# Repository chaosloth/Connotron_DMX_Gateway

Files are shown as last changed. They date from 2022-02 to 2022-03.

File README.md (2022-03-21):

# ESP32 ArtNet to DMX Gateway

This project allows for receiving ArtNet messages via WIFI and transmitting ANSI-ESTA E1.11 DMX-512A using an Espressif ESP32. It is based on two libraries for ArtNet and DMX messaging which individually have a ton of configurability. By default this project will open up a WIFI configuration portal after a _double reset_ where the WIFI credentials and ArtNet Universe may be configured. The output circuitry has been texted with [MAX485 TTL UART to RS485](https://core-electronics.com.au/ttl-uart-to-rs485-converter-module.html) module along with MAX485 chips directly. 

Click the link below to see it in action

See it in action

## Contents

- [Overview](#overview)
  - [Flow](#flow)
  - [Stack](#stack)
- [Prototype 1](#prototype-1)
- [Prototype 2](#prototype-2)
  - [Schematic](#schematic)
  - [PCB Layout](#pcb-layout)
  - [PCB Render](#pcb-render)
  - [Enclosure](#enclosure)
- [Library Installation](#library-installation)
  - [ArtNet](#artnet)
  - [ESP DMX](#esp-dmx)
  - [WIFI Manager](#wifi-manager)
- [Hardware](#hardware)
  - [UART Pins](#uart-pins)

## Overview

### Stack
Building on the ESP Core, this project can accept physical DMX connections (RJ45, XLR) along with connecting to WIFI to accept ArtNet messagse. Whilst it is possible to accept ArtNet broadcast messages, the reality of WIFI connections is that many packets are lost, hence it is recommended that UNICAST be configured for the upstream ArtNet controller.

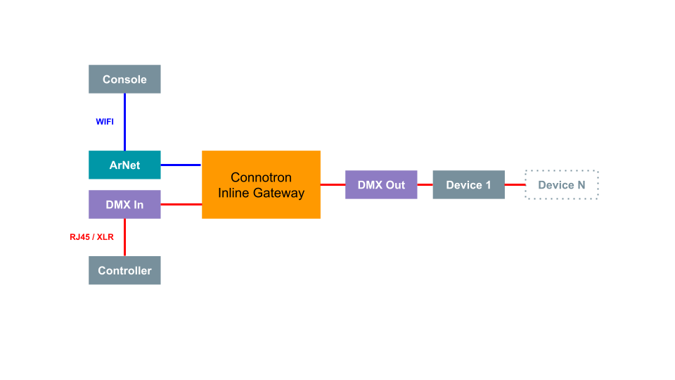
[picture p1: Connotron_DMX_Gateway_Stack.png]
Stack


### Flow

All incoming DMX messages are forwarded by default to the DMX Out port unless ArtNet messaging is being received, in which case Incoming DMX messages are dropped and the configured ArtNet universe messages are sent via the DMX Out port. The Gateway is configured to forward exactly one ArtNet universe to the DMX Output port. A Universe ID is configured as part of the WIFI setup, by default Universe 1 is configured.

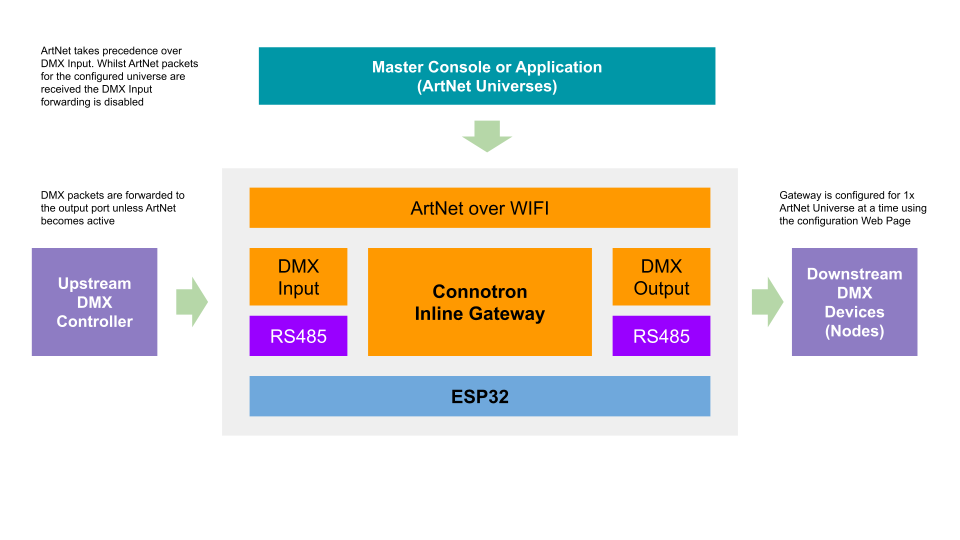
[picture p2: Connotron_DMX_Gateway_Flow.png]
Flow


## Prototype 0

The proto board uses off the shelf modules hand soldered with perfboard

Proto Board Proto

## Prototype 1

The proto board uses off the shelf modules to enable RS485 (DMX) communication between devices, though you can use the MAX485 chip directly. Basic board outline via EasyEDA.

Proto Board Proto

## Prototype 2

A second version of the board created use EasyEDA and Fusion 360 for custom board and case design.

*Note*: ESP module does not have any flash, use version v3

### Schematic

Schematic

### PCB Layout

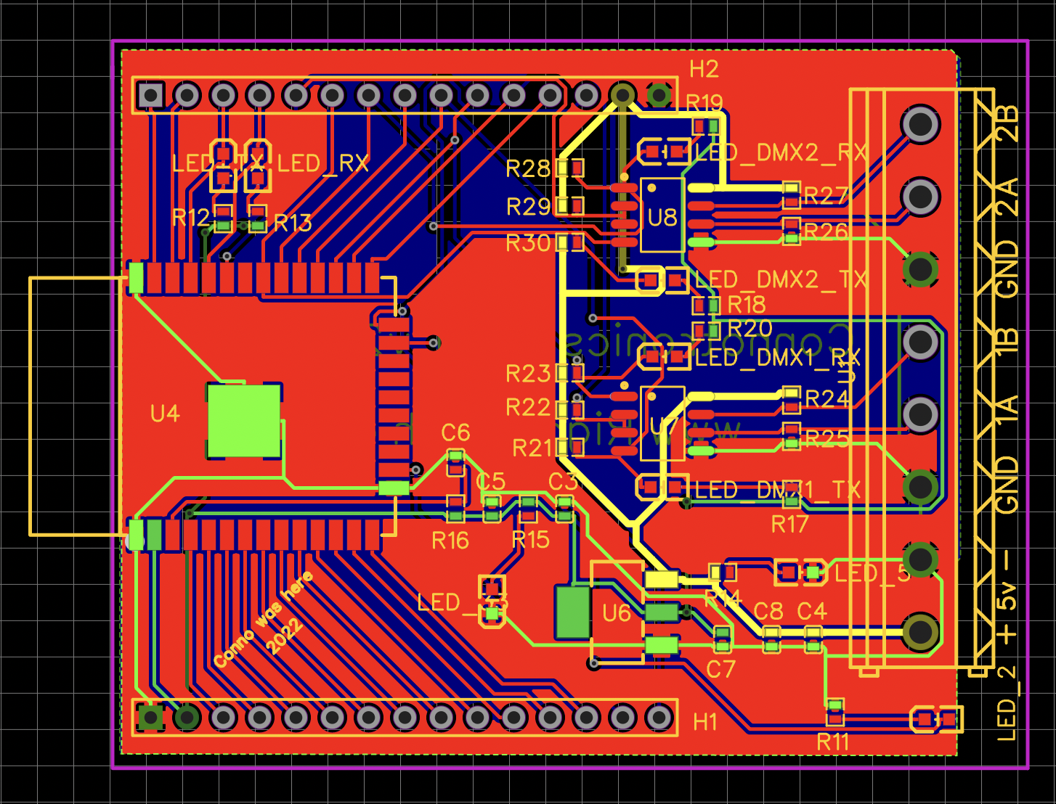
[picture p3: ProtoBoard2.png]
Silkscreen


### PCB Render

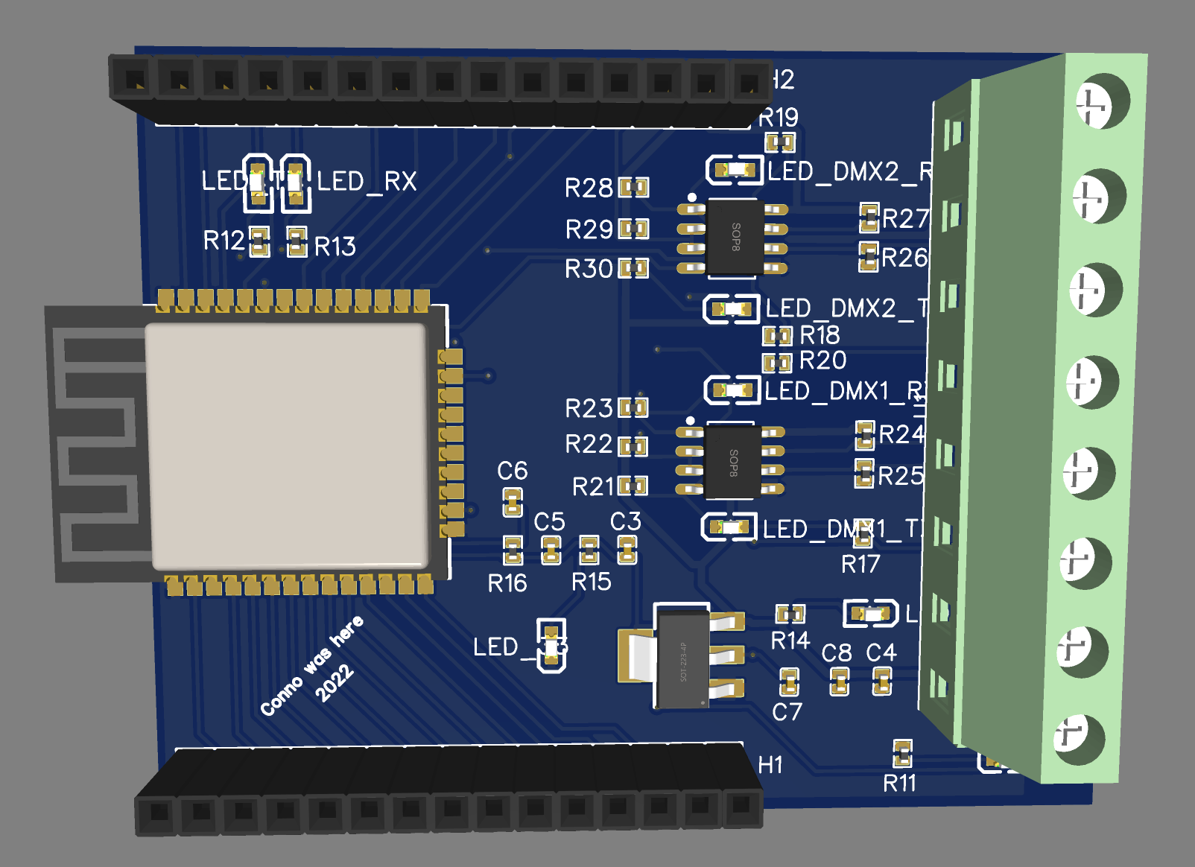
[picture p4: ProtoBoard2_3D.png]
3D Render


### Enclosure

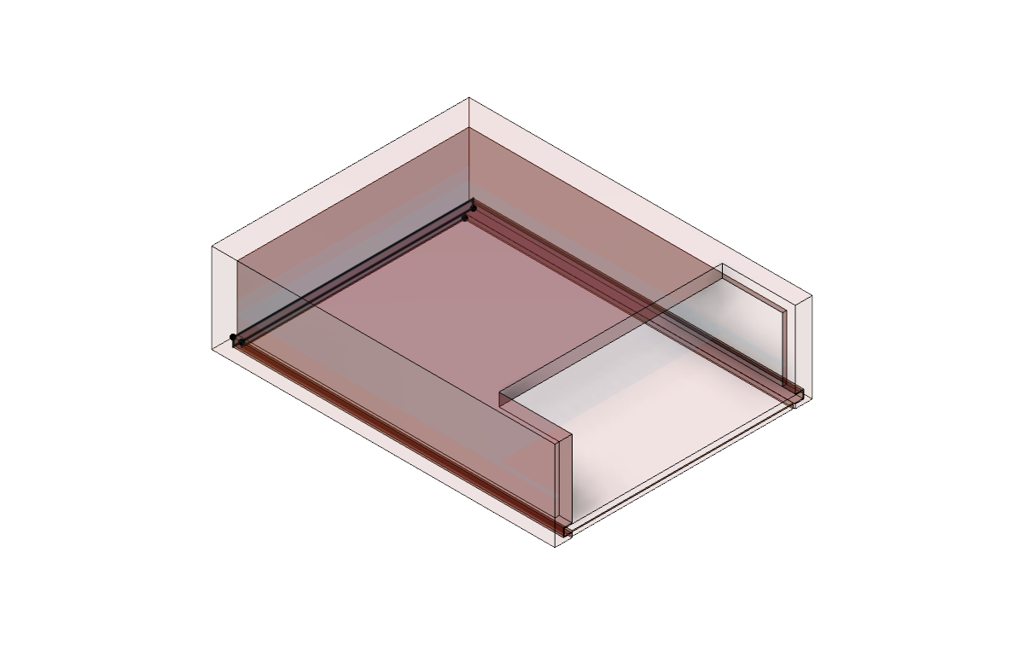
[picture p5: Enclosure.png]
Enclosure


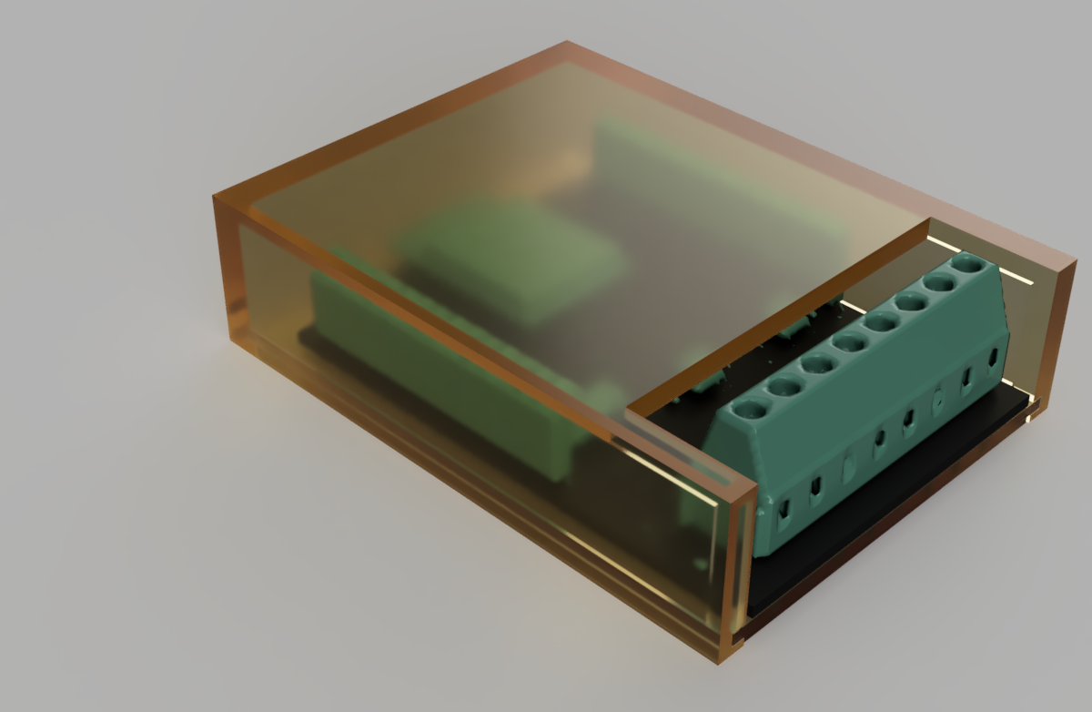
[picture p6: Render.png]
Render


## Library Installation

This project requires the Arduino-ESP32 framework version 2.0.0 or newer. To install the correct framework, follow Espressif's instructions on the Arduino-ESP32 documentation page [here](https://docs.espressif.com/projects/arduino-esp32/en/latest/installing.html).

### ArtNet

This project uses [ArtnetWifi](https://github.com/rstephan/ArtnetWifi) from Stephan Ruloff as the means to receive ArtNet packets

Tested with 1.4.0 -- Install this via Arduino Library Manager

### ESP DMX

This project uses [esp_dmx](https://github.com/someweisguy/esp_dmx) from Mitch Weisbrod as the means to transmit and receive DMX messages

Tested with 1.1.3 -- Install this via Arduino Library Manager

### WIFI Manager

This project uses [ESP Async WIFI Manager](https://github.com/khoih-prog/ESPAsync_WiFiManager) from Khoi Hoangx as the means to configure WIFI credentials

Tested with 1.12.0 -- Install this via Arduino Library Manager

## Hardware

RS485 to TTL UART is performed by the MAX485 (or similar) IC. Wired as follows. UART 2 on the ESP is used for communications on the default pins. This can be changed to any available UART if required, note that the ESP32 has the ability to remap UART pins to any GPIO, with the esp_dmx library providing a function to set the pins. 

Note that if this is setup to transmit DMX messages only, then RE, DE can simply be pulled low to GND

#### DMX Port - Output

Note receive is not connected in this case

| Function			  | ESP PIN | MAX PIN 	|
| --- |:---:| ---:|
| Transmit			  | 17			 | DI 		 |
| Transmit Enable	| 4 			 | RE 	 	|
| Receive Enable	| 4 			 | DE 	 	|
| Receive			 | NC (16)	 | RO 	 	|

#### DMX Port - Input

Note transmit is not connected in this case

| Function | ESP PIN | MAX PIN |
| --- |:---:| ---:|
| Transmit | NC (19) | DI |
| Transmit Enable | 21 | RE |
| Receive Enable  | 21 | DE |
| Receive | 18 | RO |

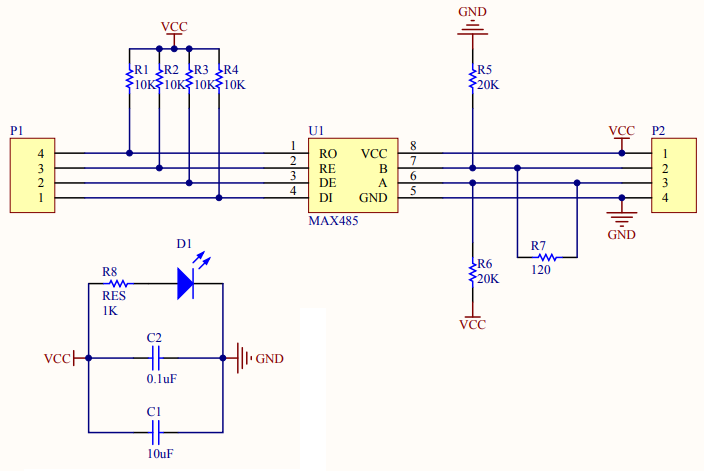
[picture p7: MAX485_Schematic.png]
Schematic MAX485


### UART Pins

Use the esp_dmx function call to change the UART GPIO pins to non-standard pinouts

```
esp_err_t dmx_set_pin(dmx_port_t dmx_num, int tx_io_num, int rx_io_num, int rts_io_num)
```

Example:
```
dmx_port_t dmxPort = 2;
int transmitPin = 17;
int receivePin = 16;
int enablePin = 21;

dmx_set_pin(dmxPort, transmitPin, receivePin, enablePin);
```

## Uploading Firmware
### Manually

Manual upload to board, using **using esptool v3.2**
```
esptool.py --port /dev/cu.usbserial-1110  --before default_reset \
  --after hard_reset write_flash -z --flash_mode dio \
  --flash_freq 80m  \
  0xe000 boot_app0.bin \
  0x1000 ESP32_ArtNet_DMX_Gateway.ino.bootloader.bin \
  0x10000 ESP32_ArtNet_DMX_Gateway.ino.bin \
  0x8000 ESP32_ArtNet_DMX_Gateway.ino.partitions.bin
  ```

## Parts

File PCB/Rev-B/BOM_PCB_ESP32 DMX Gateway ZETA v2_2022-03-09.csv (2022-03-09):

ID | Name | Designator | Footprint | Quantity | Manufacturer Part | Manufacturer | Supplier | Supplier Part | Price | Pins | 3DModel | JLCPCB Part Class | LCSC Assembly | Contributor | SMT Type | image | link
1 | 19-217/GHC-YR1S2/3T | LED_2,LED_5,LED_33,LED_DMX1_RX,LED_DMX1_TX,LED_DMX2_RX,LED_DMX2_TX,LED_RX,LED_TX | LED0603-R-RD | 9 | 19-217/GHC-YR1S2/3T | EVERLIGHT | LCSC | C72043 | 0.029 | 2 | LED0603_L1.6-W0.8-H0.6 | Basic Part |  | 官方封装库 |  |  | https://lcsc.com/product-detail/Light-Emitting-Diodes-LED_Hubei-KENTO-Elec-0603-Green_C12624.html
2 | DB127V-5.0-8P-GN-S | U1 | CONN-TH_8P-P5.08_DB128L-5.0-8P-GN-S | 1 | DB128L-5.0-8P-GN-S | DIBO | LCSC | C430596 | 0.528 | 8 | CONN-TH_8P-P5.08_DB128L-5.0-8P-GN-S | Extended Part |  | LCSC |  |  | https://item.szlcsc.com/426241.html
3 | 100nF | C3,C4,C6 | C0402 | 3 | CL05B104KO5NNNC | SAMSUNG | LCSC | C1525 | 0.001 | 2 | C0402_L1.0-W0.5-H0.5 |  | Yes | layout | Basic |  | https://item.szlcsc.com/319796.html
4 | 10uF | C5,C7,C8 | C0402 | 3 | CL05A106MQ5NUNC | SAMSUNG | LCSC | C15525 | 0.005 | 2 | C0402_L1.0-W0.5-H0.5 |  | Yes | layout | Basic |  | https://item.szlcsc.com/319796.html
5 | HDR-F-2.54_1x15 | H1,H2 | HDR-F-2.54_1X15 | 2 |  |  | LCSC | C124408 | 0.203 | 15 | HDR-F-2.54_1x15 |  |  | LCEDA_Lib
6 | 470 | R11,R12,R13,R14,R15,R17,R18,R19,R20 | R0402 | 9 | 0402WGF4700TCE | UniOhm | LCSC | C25117 | 0.001 | 2 | R0402_L1.0-W0.5-H0.5 |  | Yes | layout | Basic |  | https://item.szlcsc.com/323315.html
7 | 12K | R16 | R0402 | 1 | 0402WGF1202TCE | UniOhm | LCSC | C25752 | 0.001 | 2 | R0402_L1.0-W0.5-H0.5 |  | Yes | layout | Basic |  | https://item.szlcsc.com/323315.html
8 | 10K | R21,R22,R23,R28,R29,R30 | R0402 | 6 | 0402WGF4700TCE | UniOhm | LCSC | C25117 | 0.001 | 2 | R0402_L1.0-W0.5-H0.5 |  | Yes | layout | Basic |  | https://item.szlcsc.com/323315.html
9 | 20K | R24,R25,R26,R27 | R0402 | 4 | 0402WGF4700TCE | UniOhm | LCSC | C25117 | 0.001 | 2 | R0402_L1.0-W0.5-H0.5 |  | Yes | layout | Basic |  | https://item.szlcsc.com/323315.html
10 | AMS1117-3.3 | U6 | SOT-223-3_L6.5-W3.4-P2.30-LS7.0-BR | 1 | AMS1117-3.3 | AMS | LCSC | C6186 | 0.18 | 4 | SOT-223-4P_L6.5-W3.5-H1.6-LS7.0-P2.30 |  | Yes | LCSC | Basic | //image.lceda.cn/szlcsc/C6186.jpg | https://item.szlcsc.com/410724.html
11 | MAX485ED | U7,U8 | SOP-8_L4.9-W3.9-P1.27-LS6.0-BL | 2 | MAX485ED | HTC Korea TAEJIN Tech | LCSC | C481667 | 0.395 | 8 | SOP-8_L4.9-W3.9-H1.45-LS6.0-P1.27 | Extended Part |  | LCSC |  |  | https://item.szlcsc.com/383602.html
12 | ESP32-WROOM-32E(16MB) | U4 | WIFI-SMD_ESP32-WROOM-32E-A | 1 | ESP32-WROOM-32E(16MB) | Espressif Systems | LCSC | C701343 | 5.11 | 47 |  | Extended Part |  | LCSC |  |  | https://img.jlc.com/pdf/applyPasteComponent/2022-02-19/286240A/9c72ea5c3be84b1e91d87726b093e6ca/esp32-wroom-32e_esp32-wroom-32ue_datasheet_cn.pdf

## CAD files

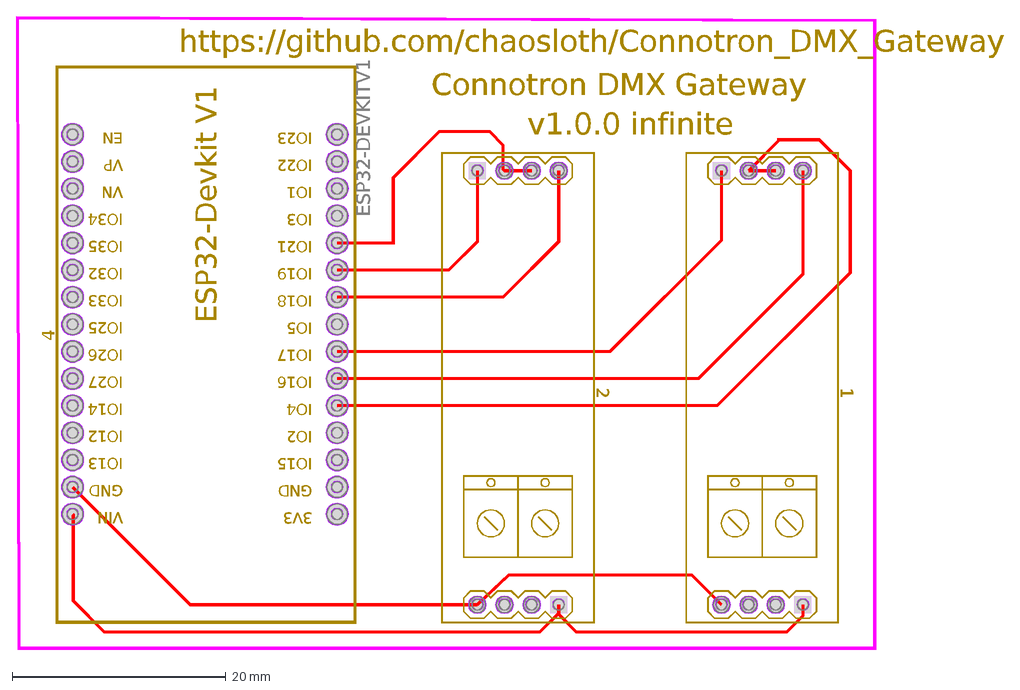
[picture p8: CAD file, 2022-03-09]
Enclosure/Rev A Board/V1/PCB_ESP32 DMX Gateway_2022-03-01.dxf
https://github.com/chaosloth/Connotron_DMX_Gateway
Connotron DMX Gateway
v1.0.0 infinite
1
2
4
3V3
GND
IO15
IO2
IO4
IO16
IO17
IO5
IO18
IO19
IO21
IO3
IO1
IO22
IO23
VIN
IO13
IO12
IO14
IO27
IO26
IO25
IO33
IO32
IO35
IO34
VN
VP
EN
ESP32-Devkit V1
ESP32-DEVKITV1

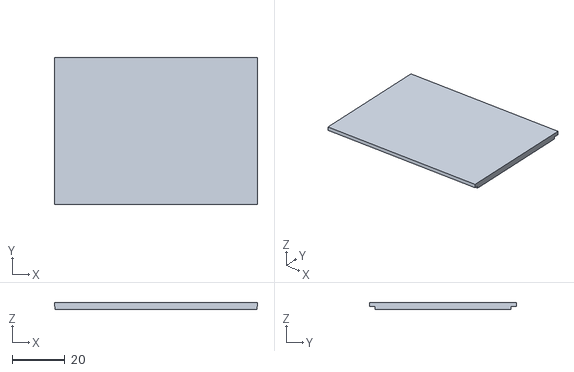
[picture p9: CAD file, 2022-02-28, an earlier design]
Enclosure/V2/Lid.stl
77.0 x 55.6 x 2.80

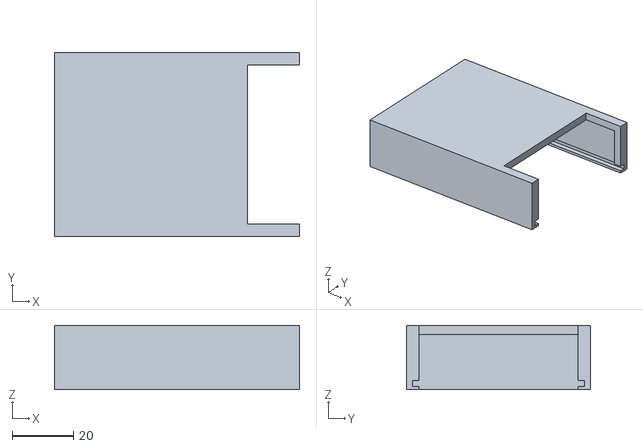
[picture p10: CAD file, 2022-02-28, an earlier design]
Enclosure/V3/Middle body.stl
80.0 x 60.0 x 20.9

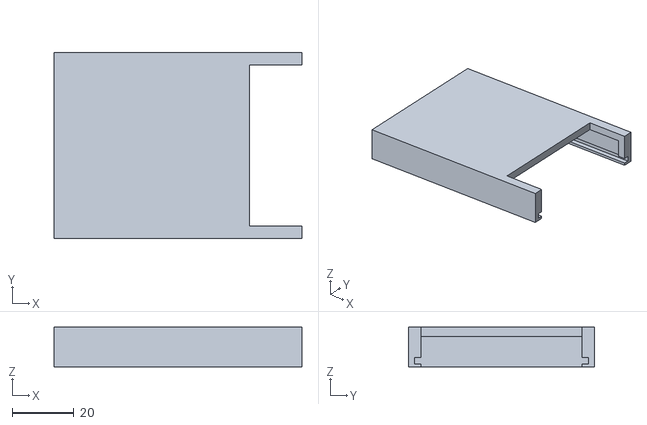
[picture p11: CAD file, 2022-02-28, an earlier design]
Enclosure/V2/Combineed box.stl
80.0 x 60.0 x 12.9

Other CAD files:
Enclosure/V3/Lid.stl

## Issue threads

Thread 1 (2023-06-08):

trouble with webserver

maracasas, 2023-06-08:
greetings.

i successfully compiled this file:
https://github.com/chaosloth/Connotron_DMX_Gateway/blob/master/ESP32_ArtNet_DMX_Gateway/ESP32_ArtNet_DMX_Gateway.ino

i see the esp32 is receiving artnet data, so i assume the device and bin works as intended

but for dear life, i can not access the webserver

i tried using the ip that m router give to the esp32, and the host name that shows in serial printer on arduino ide.

can you point me where is the problem please?

i am using all the libraries you shared + ESPAsyncWebServer from the same author of ESPAsync_WiFiManager

chaosloth, 2023-07-13:
Hey @maracasas sorry to hear it's not working, can you send me some additional info to help debug, e.g.

- What board are you using?
- Can you add the serial output upon startup?
- Can you ping the <whatever>.local mDNS name?
- Can you telnet to the IP/DNS on port 80?

chaosloth, 2023-07-20:
Cool glad it worked out. You're right it is only used for OTA, you could of course roll your own web interface and call api end points to configure it.

As for changing the DMX (IN/OUT) yes this is certainly possible, you can also add more DMX interfaces, so long as you have free UARTS.

Aside note, I have a bunch of left over board with (Prototype 1). I'm happy to send you a couple. Direct message me on LinkedIn and I'll send them to you (no charge) https://www.linkedin.com/in/christopherjamesconnolly

rvbcrs, 2023-09-04:
@maracasas @chaosloth Hi, I'm also trying to compile the ino file, but I tried in PlatformIO and in Arduino IDE and both gave me a massive amount of errors! Can you tell me how to compile this?

DeverosTV, 2023-09-04:
> @maracasas @chaosloth Hi, I'm also trying to compile the ino file, but I tried in PlatformIO and in Arduino IDE and both gave me a massive amount of errors! Can you tell me how to compile this?

yes i think the biggest issue you have with arduino ide, is that you updated the esp32 board to the latest version. that gave me errors or the board was not working.

right now i am using esp32 version 2.0.9 from espresiff
also aside from the libraries that are mentioned in the  main page i am also using ESPAsyncWebServer from the same author of ESPAsync_WiFiManager

it should be compiling after those changes, at least mine are

chaosloth, 2023-09-06:
> @maracasas @chaosloth Hi, I'm also trying to compile the ino file, but I tried in PlatformIO and in Arduino IDE and both gave me a massive amount of errors! Can you tell me how to compile this?

Hey mate - can you pls open a new issue for this and give the output that you see.

I've been building using Platform.IO for the most recent builds, keen to see what you're getting

I'm going to close this issue as the OP has indicated it's resolved

Closed 2023-09-06.

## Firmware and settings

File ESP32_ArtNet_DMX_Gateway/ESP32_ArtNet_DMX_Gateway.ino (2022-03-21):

/*
  ============================================================
  Copyright (c) 2022 Christopher Connolly
  Project:     ArtNet to DMX Gateway
  Author:      Christopher Connolly
  Last update: 22.02.2022
  Description: ESP32 using MAX485 for RS485 communication
  License:     GNU GPL 3, see libraries for respective licenes too

  Dependencies & Kudos:
  https://github.com/rstephan/ArtnetWifi from Stephan Ruloff 2016-2019
  https://github.com/someweisguy/esp_dmx from By Mitch Weisbrod 2021
  https://github.com/khoih-prog/ESPAsync_WiFiManager from Khoi Hoangx
  ============================================================

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
  You should have received a copy of the GNU General Public License
  along with this program. If not, see <http://www.gnu.org/licenses/>.
*/

#define VERSION                   "1.4.0"               // Version
#define DEVICE_NAME               "ConnoDMX"          // Prefix of access point for inital config
#define WIFI_PASSWORD             "infinite"          // Password for built-in AP during config mode
#define WIFICHECK_INTERVAL        5000L               // How often to check WIFI connection
#define OTA_USERNAME              "infinite"          // Password for OTA firmware updates
#define OTA_PASSWORD              "infinite"          // Password for OTA firmware updates
#define BUTTONCHECK_INTERVAL      10000L              // How often to check for button press
#define USE_ESP_WIFIMANAGER_NTP   false               // Recommended to be false for mobile clients
#define LED_BUILTIN               2                   // Status LED to use
#define DMX_RX_TIMEOUT            50                  // Instead of DMX_RX_PACKET_TOUT_TICK
#define ART_NET_TIMEOUT_MS        5000                // Time in ms to wait for ArtNet packet before declaring disconnect
#define CONFIG_WIFI_PIN           15                  // Built in button on ESP-Dev is 0, use 15 for production boards
#define NUM_WIFI_CREDENTIALS      1                   // Number of APs to store creds for
#define ESP_DMX_VERSION           "1.1.3"             // Version of DMX built-with

#include "nvs_flash.h"
#include <esp_dmx.h>
#include <Arduino.h>
#include <ArduinoOTA.h>
#include "ArtnetWifi.h"
#include <WiFiMulti.h>
#include <ESPAsync_WiFiManager.h>
#include <Update.h>
#include <ESPmDNS.h>
#include <AsyncElegantOTA.h>
#include "ESPAsyncWebServer.h"
#include "SPIFFS.h"

char LOGO[] PROGMEM = R"(

  .oooooo.                                               oooooooooo.   ooo        ooooo ooooooo  ooooo 
 d8P'  `Y8b                                              `888'   `Y8b  `88.       .888'  `8888    d8'  
888           .ooooo.  ooo. .oo.   ooo. .oo.    .ooooo.   888      888  888b     d'888     Y888..8P    
888          d88' `88b `888P"Y88b  `888P"Y88b  d88' `88b  888      888  8 Y88. .P  888      `8888'     
888          888   888  888   888   888   888  888   888  888      888  8  `888'   888     .8PY888.    
`88b    ooo  888   888  888   888   888   888  888   888  888     d88'  8    Y     888    d8'  `888b   
 `Y8bood8P'  `Y8bod8P' o888o o888o o888o o888o `Y8bod8P' o888bood8P'   o8o        o888o o888o  o88888o 
                                                                                                       
)";

// Use wifiMulti
WiFiMulti wifiMulti;

// Wifi configuration portal settings
String unique_hostname = "ConnoDMX_" + String(ESP_getChipId(), HEX);   // Suffix AP name with Chip ID
String ssid = unique_hostname;
String password = "";   // No password

// Status LED, blinks when all is groovy
boolean ledState = false;
const int PIN_LED       = 2;

// Web Server
AsyncWebServer webServer(80);

// WIFI Manager
bool      initialConfig = false;
#if !( USING_ESP32_S2 || USING_ESP32_C3 )
DNSServer dnsServer;
#endif

#if ( USING_ESP32_S2 || USING_ESP32_C3 )
ESPAsync_WiFiManager ESPAsync_wifiManager(&webServer, NULL, DEVICE_NAME);
#else
ESPAsync_WiFiManager ESPAsync_wifiManager(&webServer, &dnsServer, DEVICE_NAME);
#endif

WiFiUDP UdpSend;
ArtnetWifi artnet;

/* First, lets define the hardware pins that we are using with our ESP32. We
  need to define which pin is transmitting data and which pin is receiving data.
  DMX circuits also often need to be told when we are transmitting and when we are
  receiving data. We can do this by defining an enable pin. */
int dmxOutTransmitPin = 17;
int dmxOutReceivePin = 16;
int dmxOutEnablePin = 4;

int dmxInTransmitPin = 19;
int dmxInReceivePin = 18;
int dmxInEnablePin = 21;

/* Next, lets decide which DMX ports to use. The ESP32 has either 2 or 3 UART ports.
  Port 0 is typically used to transmit serial data back to your Serial Monitor,
  so we shouldn't use that port. Lets use port 2! */
dmx_port_t dmxInPort = 1;   // UART 1 - Pins not exposed on board, must remap GPIOs
dmx_port_t dmxOutPort = 2;  // UART 2 - Default pins used

/* Now we want somewhere to store our DMX data. Since a single packet of DMX
  data can be up to 513 bytes long, we want our array to be at least that long.
  This library knows that the max DMX packet size is 513, so we can fill in the
  array size with `DMX_MAX_PACKET_SIZE`. */
byte dataOut[DMX_MAX_PACKET_SIZE];
byte dataIn[DMX_MAX_PACKET_SIZE];

/* The last variable that we need to read DMX is a queue handle. It's not
  important to know all the details about queues right now. All that you need to
  know is that when we receive a packet of DMX, our queue will be populated with
  an event that informs us that we've received new data. This allows us to wait
  until a new packet is received. Then we can then process the incoming data! */
QueueHandle_t queue;

/* The last few main variables that we need allow us to log data to the Serial
  Monitor. In this sketch, we want to log some information about the DMX we've
  received once every second. We'll declare a timer variable that will keep track
  of the amount of time that has elapsed since we last logged a serial message.
  We'll also want a flag that tracks if we are connected to the DMX controller so
  that we can log when we connect and when we disconnect. */
unsigned int timer = 0;
bool dmxIsConnected = false;

/* These variables track if we are receiving ArtNet packets, if so ignore DMX In
   otherwise forward DMX packets from input to DMX Out port. */
bool artNetIsConnected = false;
unsigned int lastArtNetPacket = 0;


#define UniverseLabel         "ArtNet Universe"
int myUniverse = 0;
ESPAsync_WMParameter p_UniverseID(UniverseLabel, "ArtNet Universe", "1", 1);

/* This variables stores the init status of OTA and web server. Initially false and set to true
  by the initWIFI function after WIFI Configuration Portal has been run */
bool initOtaComplete = false;

/* Variables to store the current status checks for WIFI and button presses */
//static ulong checkstatus_timeout  = 0;
static ulong checkbutton_timeout    = 0;
static ulong checkwifi_timeout      = 0;

void setup() {
  nvs_flash_init();

  pinMode(LED_BUILTIN, OUTPUT);
  pinMode(CONFIG_WIFI_PIN, INPUT_PULLUP);
  // set-up serial for debug output
  Serial.begin(115200); while (!Serial); delay(200);
  Serial.println(LOGO);
  Serial.println("\nStarting ConnoDMX Gateway Version " + String(VERSION));
  Serial.println("\t WIFI Manager: " + String(ESP_ASYNC_WIFIMANAGER_VERSION));
  Serial.println("\t ESP_DMX: " + String(ESP_DMX_VERSION));

  if(!SPIFFS.begin(true)){
    Serial.println("An Error has occurred while mounting SPIFFS");
    return;
  }

  initDMXIn();                    // Setup DMX port to use UART1
  initDMXOut();                   // Setup DMX port to use UART2
  initArtNet();                   // Setup ART NET
  connectOrConfigureWifi();       // Connect to WIFI
}

void initArtNet() {
  // This will be called for each packet received
  artnet.setArtDmxCallback(onArtNetFrame);
  artnet.begin();
}

void connectOrConfigureWifi() {
  if (initialConfig) {
    Serial.println(F("Inital Config mode. Starting Portal"));
    digitalWrite(PIN_LED, HIGH);

    // Add custom configurable ArtNet Universe Number
    ESPAsync_wifiManager.addParameter(&p_UniverseID);

    // Set timeout on configuration portal
    ESPAsync_wifiManager.setConfigPortalTimeout(30);

    if (!ESPAsync_wifiManager.startConfigPortal(ssid.c_str(), WIFI_PASSWORD)) {
      Serial.println(F("Not connected to WiFi"));
    } else {
      Serial.println(F("Wifi connected"));
      String Router_SSID = ESPAsync_wifiManager.WiFi_SSID();
      String Router_Pass = ESPAsync_wifiManager.WiFi_Pass();
      Serial.println("WIFI Manager Self-Stored: SSID = " + Router_SSID + ", Pass = " + Router_Pass);
      wifiMulti.addAP(Router_SSID.c_str(), Router_Pass.c_str());
    }

    /* Get ArtNet Universe ID from the WIFI manager. This is set during
      initial configuration and is retained in EEPROM by the WIFI Manager,
      if for some reason it isn't set it will default to Universe 0
    */
    Serial.printf("Configured Universe ID: %d \n", atoi(p_UniverseID.getValue()));
    myUniverse = atoi(p_UniverseID.getValue());
    initialConfig = false;
    digitalWrite(PIN_LED, LOW);

  } else {
    Serial.println(F("Normal mode. Entering WIFI_STA mode"));
    String Router_SSID = ESPAsync_wifiManager.WiFi_SSID();
    String Router_Pass = ESPAsync_wifiManager.WiFi_Pass();
    Serial.println("WIFI Manager Self-Stored: SSID = " + Router_SSID + ", Pass = " + Router_Pass);
    WiFi.mode(WIFI_STA);
    WiFi.begin();
  }
}

void initOTA() {
  // Exit if already init
  if (initOtaComplete) return;

  // Hostname defaults to esp3232-[MAC]
  ArduinoOTA.setHostname(unique_hostname.c_str());

  // Setup authentication for OTA
  ArduinoOTA.setPassword(OTA_PASSWORD);

  ArduinoOTA
  .onStart([]() {
    String type;
    if (ArduinoOTA.getCommand() == U_FLASH)
      type = "sketch";
    else // U_SPIFFS
      type = "filesystem";

    // NOTE: if updating SPIFFS this would be the place to unmount SPIFFS using SPIFFS.end()
    Serial.println("OTA Start updating " + type);
  })
  .onEnd([]() {
    Serial.println("\nOTA Update Complete");
  })
  .onProgress([](unsigned int progress, unsigned int total) {
    Serial.printf("Progress: %u%%\r", (progress / (total / 100)));
  })
  .onError([](ota_error_t error) {
    Serial.printf("Error[%u]: ", error);
    if (error == OTA_AUTH_ERROR) Serial.println("Auth Failed");
    else if (error == OTA_BEGIN_ERROR) Serial.println("Begin Failed");
    else if (error == OTA_CONNECT_ERROR) Serial.println("Connect Failed");
    else if (error == OTA_RECEIVE_ERROR) Serial.println("Receive Failed");
    else if (error == OTA_END_ERROR) Serial.println("End Failed");
  });

  ArduinoOTA.begin();
  Serial.println("OTA Ready");

  /*use mdns for host name resolution*/
  if (!MDNS.begin(DEVICE_NAME)) { // http://<DEVICE_NAME>.local
    Serial.println("Error setting up MDNS responder!");
  } else {
    Serial.println("mDNS configured: " + String(DEVICE_NAME) + ".local");
  }

  webServer.on("/index.html", HTTP_GET, [](AsyncWebServerRequest *request){
    request->send(SPIFFS, "/index.html","text/html");
  });

  webServer.on("/", HTTP_GET, [](AsyncWebServerRequest *request){
    request->send(SPIFFS, "/index.html","text/html");
  });

  webServer.on("/studio.png", HTTP_GET, [](AsyncWebServerRequest *request){
    request->send(SPIFFS, "/studio.png","image/png");
  });

  webServer.onNotFound([](AsyncWebServerRequest *request){
    request->send(404);
  });
    
  // Configure ElegantOTA with username and password
  AsyncElegantOTA.begin(&webServer, OTA_USERNAME, OTA_PASSWORD);
  webServer.begin();
  MDNS.addService("http", "tcp", 80);
  
  Serial.println("HTTP server started");
  initOtaComplete = true;
}

void initDMXIn() {
  /* Configure the DMX hardware to the default DMX settings and tell the DMX
    driver which hardware pins we are using. */
  dmx_config_t dmxInConfig = DMX_DEFAULT_CONFIG;
  dmx_param_config(dmxInPort, &dmxInConfig);
  dmx_set_pin(dmxInPort, dmxInTransmitPin, dmxInReceivePin, dmxInEnablePin);

  /* Now we can install the DMX driver! We'll tell it which DMX port to use and
    how big our DMX packet is expected to be. Typically, we'd pass it a handle
    to a queue, but since we are only transmitting DMX, we don't need a queue.
    We can write `NULL` where we'd normally put our queue handle. We'll also
    pass some interrupt priority information. The interrupt priority can be set
    to 1. */
  int queueSize = 1;
  int interruptPriority = 1;
  dmx_driver_install(dmxInPort, DMX_MAX_PACKET_SIZE, queueSize, &queue, interruptPriority);
}

void initDMXOut() {
  /* Configure the DMX hardware to the default DMX settings and tell the DMX
    driver which hardware pins we are using. */
  dmx_config_t dmxOutConfig = DMX_DEFAULT_CONFIG;
  dmx_param_config(dmxOutPort, &dmxOutConfig);
  dmx_set_pin(dmxOutPort, dmxOutTransmitPin, dmxOutReceivePin, dmxOutEnablePin);

  /* Now we can install the DMX driver! We'll tell it which DMX port to use and
    how big our DMX packet is expected to be. Typically, we'd pass it a handle
    to a queue, but since we are only transmitting DMX, we don't need a queue.
    We can write `NULL` where we'd normally put our queue handle. We'll also
    pass some interrupt priority information. The interrupt priority can be set
    to 1. */
  int queueSize = 0;
  int interruptPriority = 1;
  dmx_driver_install(dmxOutPort, DMX_MAX_PACKET_SIZE, queueSize, NULL, interruptPriority);

  /* Finally, since we are transmitting DMX, we should tell the DMX driver that
    we are transmitting, not receiving. We should also set our DMX start code
    to 0.*/
  dmx_set_mode(dmxOutPort, DMX_MODE_TX);
  dataOut[0] = 0;
}

void onArtNetFrame(uint16_t universe, uint16_t numberOfChannels, uint8_t sequence, uint8_t* dmxData) {
  ledState = !ledState;
  digitalWrite(LED_BUILTIN, ledState);

  for (int i = 1; i < numberOfChannels && i < DMX_MAX_PACKET_SIZE; ++i) {
    dataOut[i] = dmxData[i - 1];
  }

  Serial.printf("<< ArtNet Uni %u Seq %03u Chans %u => DMX: %03d - %03d %03d %03d %03d - %03d %03d %03d %03d \n", universe, sequence, numberOfChannels, dataOut[0], dataOut[1], dataOut[2], dataOut[3], dataOut[4], dataOut[5], dataOut[6], dataOut[7], dataOut[8]);

  // Only transmit our configured Universe
  if (myUniverse != universe) return;

  /* If this is the first ArtNet data we've received, lets log it! */
  lastArtNetPacket = millis();

  if (!artNetIsConnected) {
    Serial.println("ArtNet Connected and getting packets for this Universe!");
    artNetIsConnected = true;
  }

  dmx_write_packet(dmxOutPort, dataOut, DMX_MAX_PACKET_SIZE);
  dmx_tx_packet(dmxOutPort);
  dmx_wait_tx_done(dmxOutPort, DMX_TX_PACKET_TOUT_TICK);
}

void dmxInLoop() {
  /* We need a place to store information about the DMX packet we receive. We
    will use a dmx_event_t to store that packet information.  */
  dmx_event_t packet;

  /* And now we wait! The DMX standard defines the amount of time until DMX
    officially times out. That amount of time is converted into ESP32 clock ticks
    using the constant `DMX_RX_PACKET_TOUT_TICK`. If it takes longer than that
    amount of time to receive data, this if statement will evaluate to false. */
  if (xQueueReceive(queue, &packet, DMX_RX_TIMEOUT)) {

    /* If this code gets called, it means we've recieved DMX data! */

    /* We should check to make sure that there weren't any DMX errors. */
    if (packet.status == DMX_OK) {

      ledState = !ledState;
      digitalWrite(LED_BUILTIN, ledState);

      /* If this is the first DMX data we've received, lets log it! */
      if (!dmxIsConnected) {
        Serial.println("DMX In Connected!");
        dmxIsConnected = true;
      }

      /* We can read the DMX data into our buffer and increment our timer. */
      dmx_read_packet(dmxInPort, dataIn, packet.size);

      // Forward DMX IN to DMX OUT when no ArtNet packets
      if (!artNetIsConnected) {
        dmx_write_packet(dmxOutPort, dataIn, DMX_MAX_PACKET_SIZE);
        dmx_tx_packet(dmxOutPort);
        dmx_wait_tx_done(dmxOutPort, DMX_TX_PACKET_TOUT_TICK);
        Serial.printf(">> DMX In => Forward: %03d - %03d %03d %03d %03d - %03d %03d %03d %03d \n", dataIn[0], dataIn[1], dataIn[2], dataIn[3], dataIn[4], dataIn[5], dataIn[6], dataIn[7], dataIn[8]);
      } else {
        Serial.printf(">> DMX In => Ignored: %03d - %03d %03d %03d %03d - %03d %03d %03d %03d \n", dataIn[0], dataIn[1], dataIn[2], dataIn[3], dataIn[4], dataIn[5], dataIn[6], dataIn[7], dataIn[8]);
      }

    } else {
      /* Uh-oh! Something went wrong receiving DMX. */
      Serial.println("DMX In Error!");
    }
  }
}

void checkButtons() {
  static ulong current_millis;
  current_millis = millis();

  // Check WiFi every WIFICHECK_INTERVAL (10) seconds.
  if ((current_millis > checkbutton_timeout) || (checkbutton_timeout == 0))
  {
    if ((digitalRead(CONFIG_WIFI_PIN) == LOW))
    {
      Serial.println(F("\nConfiguration portal requested."));
      digitalWrite(LED_BUILTIN, HIGH);
      delay(100);
      digitalWrite(LED_BUILTIN, LOW);
      delay(100);
      digitalWrite(LED_BUILTIN, HIGH);
      delay(100);
      digitalWrite(LED_BUILTIN, LOW);
      delay(100);
      digitalWrite(LED_BUILTIN, HIGH);
      delay(100);
      digitalWrite(LED_BUILTIN, LOW);

      initialConfig = true;
      connectOrConfigureWifi();
    }

    // Increment current timeout
    checkbutton_timeout = current_millis + BUTTONCHECK_INTERVAL;
  }
}

void artNetCheck() {
  if (artNetIsConnected) {
    if (lastArtNetPacket + ART_NET_TIMEOUT_MS <= millis()) {
      artNetIsConnected = false;
      Serial.println("No ArtNet packets within timeout, setting to disconnected!");
    }
  }
}

void artnetLoop() {
  // Only perform ArtNet functions when connected to WIFI
  if ((WiFi.status() == WL_CONNECTED)) {
    artnet.read();
    artNetCheck();
  }
}

void checkWifiLoop() {
  static ulong current_millis;
  current_millis = millis();

  // Check WiFi every WIFICHECK_INTERVAL seconds.
  if ((current_millis > checkwifi_timeout) || (checkwifi_timeout == 0))
  {
    if ((WiFi.status() != WL_CONNECTED) || initialConfig) {
      Serial.println(F("WIFI not connected"));
    } else {
      Serial.print(F("WIFI Connected. Local IP: "));
      Serial.println(WiFi.localIP());
      /*
         Once we are connected to WIFI we must configure OTA update
        otherwise we will be unable to update firmware, calling initOTA
        before having a WIFI connection will cause the ESP to crash
      */
      initOTA();                        // Init OTA
      ArduinoOTA.handle();              // Check for OTA invites
    }
    checkwifi_timeout = current_millis + WIFICHECK_INTERVAL;
  }
}

void loop() {
  checkButtons();         // Check if config button pressed
  dmxInLoop();            // Process incoming DMX
  checkWifiLoop();        // Ensure WIFI connected
  artnetLoop();           // Process incoming ArtNet
}

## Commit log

2022-02-28 Proto v2 and enclosure
    [Combineed box.stl, Lid.stl, Middle body.stl]
2022-03-09 Refactor to remove dependency on WIFI being connected at startup, remove double reset detector
    [BOM_PCB_ESP32 DMX Gateway ZETA v2_2022-03-09.csv, PCB_ESP32 DMX Gateway_2022-03-01.dxf]
2022-03-21 Added web OTA, version debug, moved config PIN to 15 for production board as pullup

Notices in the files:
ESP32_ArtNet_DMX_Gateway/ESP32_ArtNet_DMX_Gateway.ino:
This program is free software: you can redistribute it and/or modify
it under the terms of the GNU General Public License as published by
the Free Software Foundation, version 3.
